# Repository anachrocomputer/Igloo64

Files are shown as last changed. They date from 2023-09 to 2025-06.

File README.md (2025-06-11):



# Igloo64 #

PCB design to adapt a 64-pin TQFP part to a standard solderless breadboard.

## The Problem ##

Many modern chips are only available in surface-mount packages.
Some have the audacity to have 64 pins, and not only that, pins on all four sides.
How can we make such a heinous package fit onto a standard solderless breadboard?

## The Solution ##

This PCB design mounts the SMD part on a vertical board that plugs into a second board
that fits on the breadboard.
The vertical board has a rounded top, reminiscent of an igloo, hence the name.

## KiCad ##

This design has been created using the Open Source CAD package KiCad, V8.0.

To install it on Ubuntu Linux:

`sudo add-apt-repository ppa:kicad/kicad-8.0-releases`

`sudo apt update`

`sudo apt install kicad`

I'm using Ubuntu 22.04 LTS which would give me the very outdated KiCad V6.0 by default.
As I write this, the latest KiCad is V8.0.5,
which is a big upgrade from the V6.0 which I started with.

## PCB Screenshot ##
Work-in-progress, showing routed tracks.
The main TQFP footprint and the four connectors surrounding it have been rotated by
45 degrees before the tracks were routed to the connectors at the bottom.
Those tracks are still a bit uneven, but they all connect correctly.
Space at the curved top of the board may be adorned with LEDs,
the bigger the better.

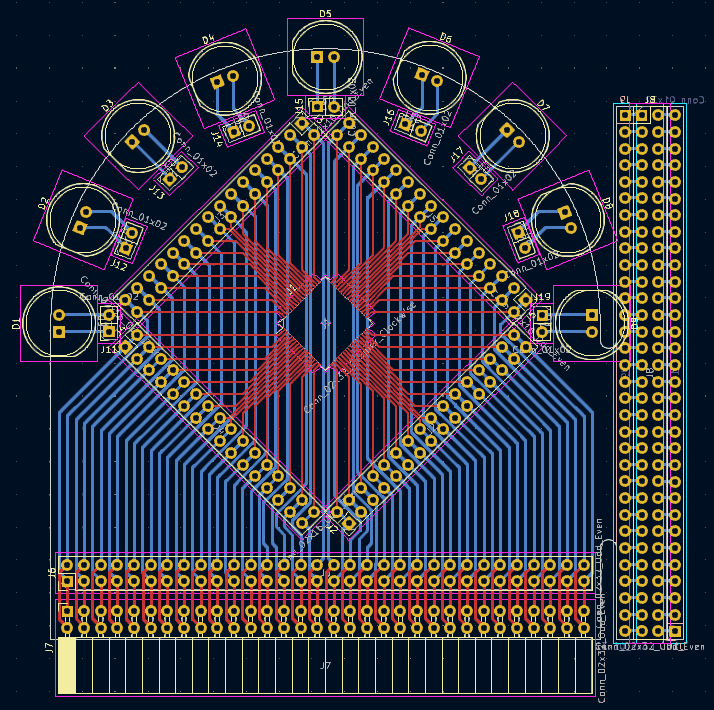
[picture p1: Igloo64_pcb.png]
PCB screenshot


## PCB 3D Render ##
KiCad's 3D rendering of the PCB as it is so far.
The portion on the right-hand side will be snapped off using mouse-bites and used
to connect the main board to the solderless breadboard.
Any colour LEDs may be fitted, up to 10mm in diameter.
The user may choose to use female headers instead of male ones,
or simply not fit headers at all if they're not needed.
Brightly coloured headers are also optional.

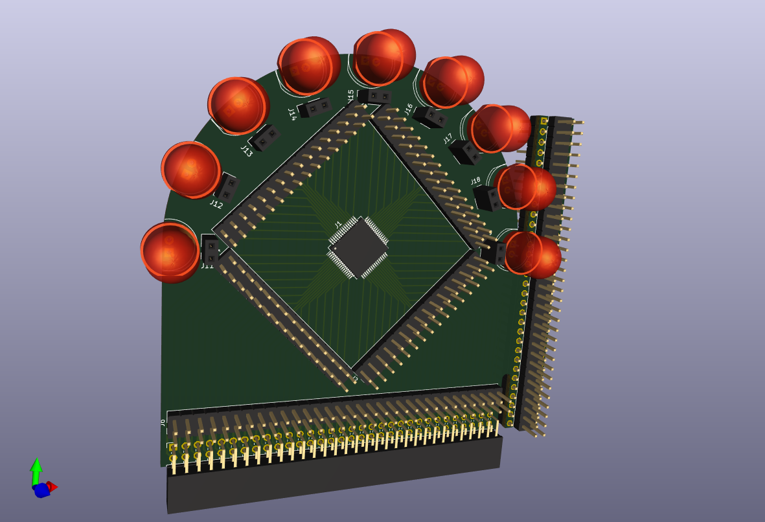
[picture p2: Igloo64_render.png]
PCB render


## PCB Photo ##
Photo of the PCB, as manufactured.

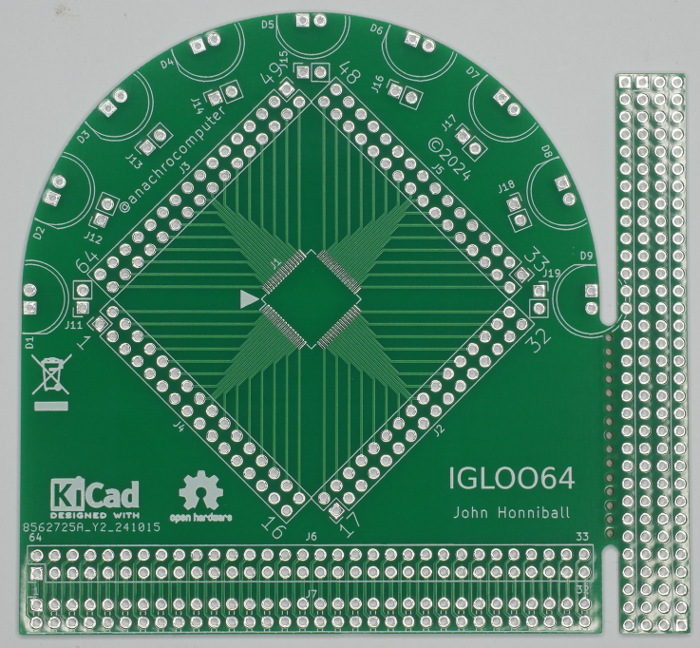
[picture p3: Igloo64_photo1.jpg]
PCB photo


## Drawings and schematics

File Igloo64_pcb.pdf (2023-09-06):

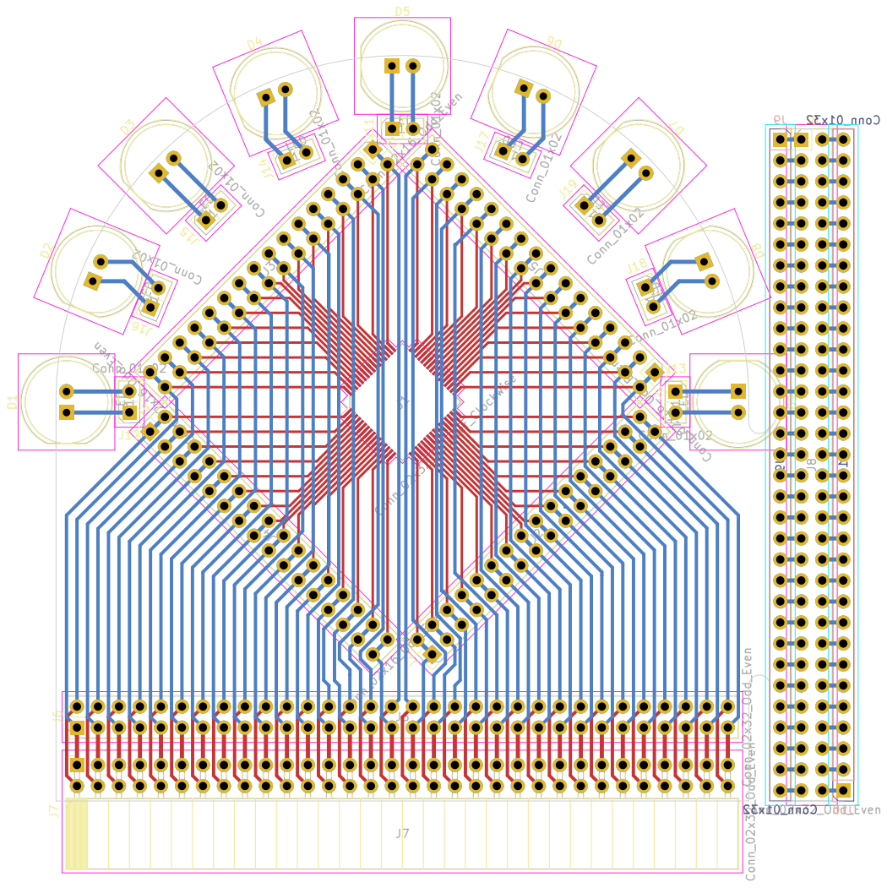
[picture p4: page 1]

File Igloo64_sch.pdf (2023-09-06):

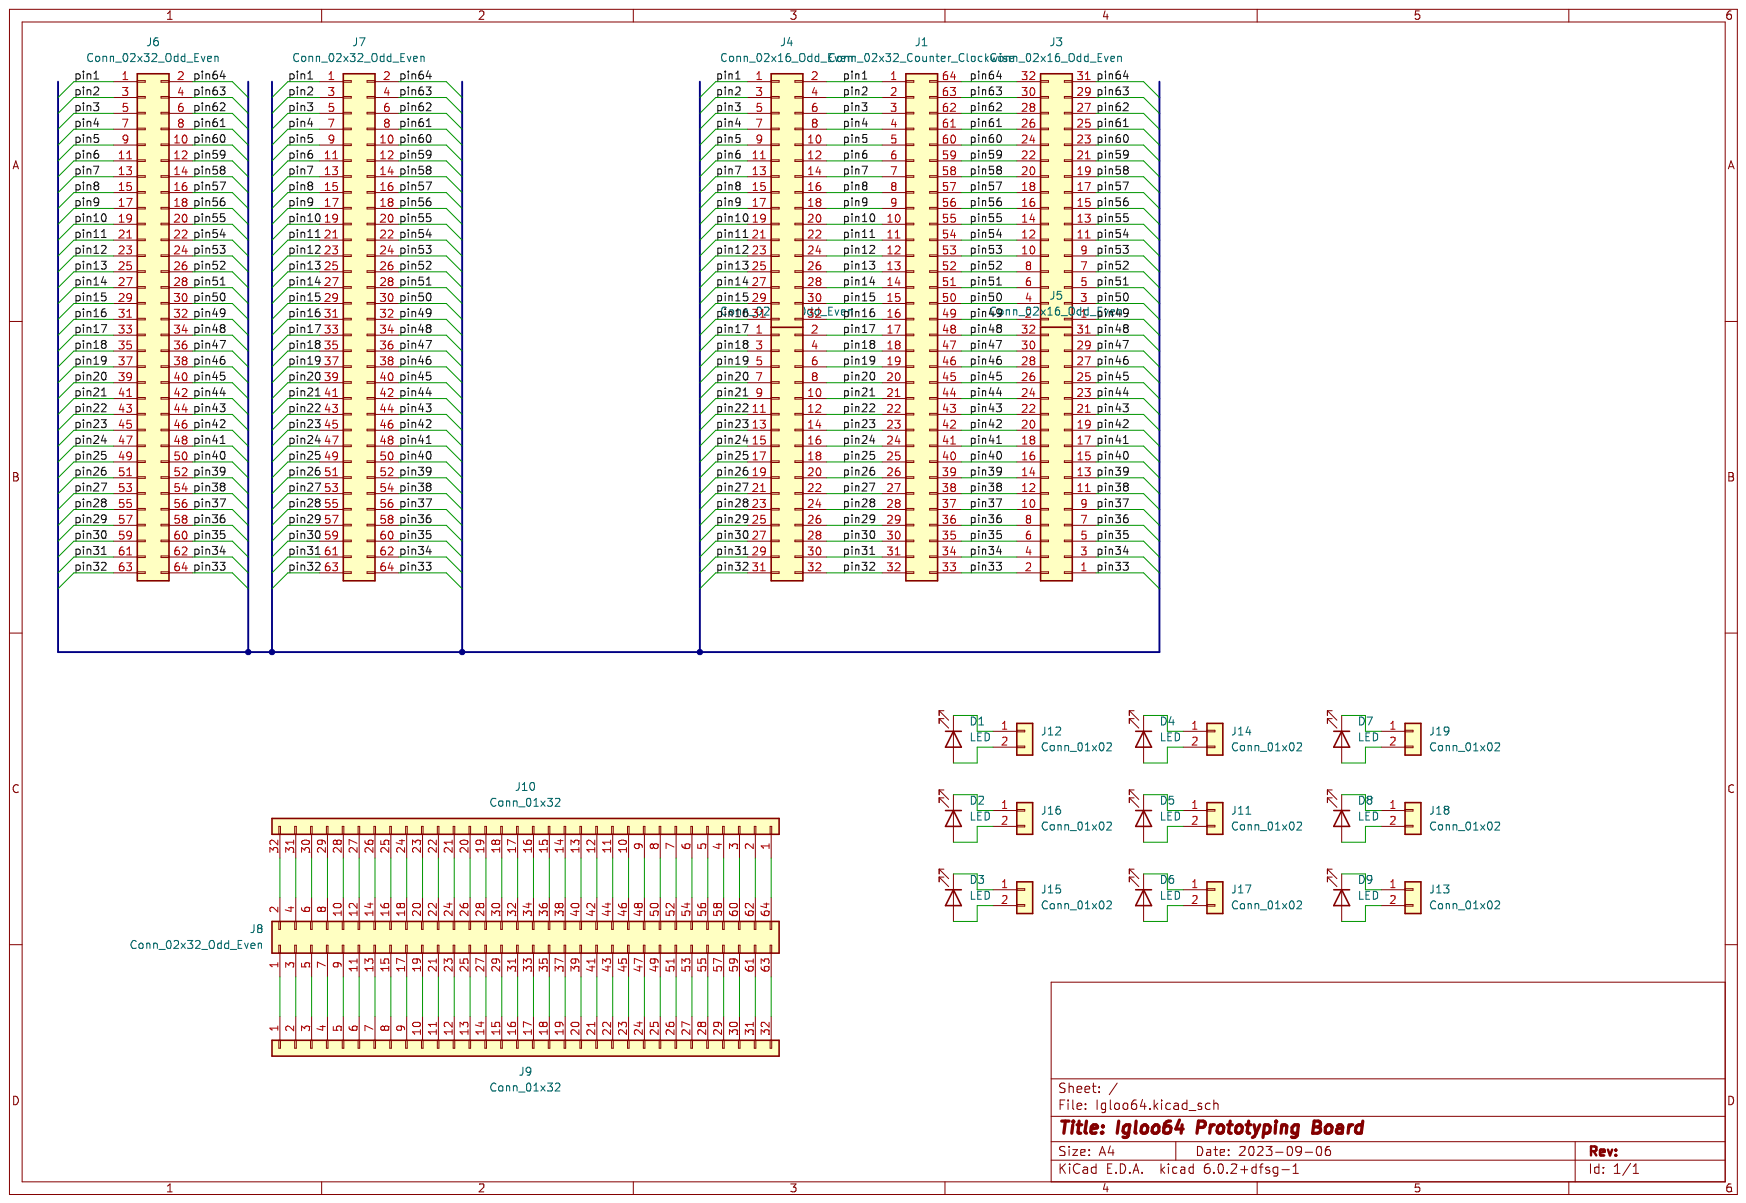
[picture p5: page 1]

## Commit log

2023-08-28 Initial commit.
    Schematic incomplete. PCB design looks OK but TQFP footprint is not in the best orientation. Secondary PCB not yet added.
    [Igloo64.kicad_pcb, Igloo64.kicad_sch]
2023-08-29 Finish wiring of buses.
    Also rotate TQFP footprint temporarily and move headers closer to it. Add tracks from TQFP to header on one side only to see how well it can be routed.
    [Igloo64.kicad_pcb, Igloo64.kicad_sch]
2023-08-29 Add secondary PCB and double up connectors.
    The secondary PCB plugs into the solderless breadboard in the same way as a 64-pin DIL chip (0.3in width). It's just connectors. Also make the ring of connectors around the TQFP footprint into 2-row 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
    [Igloo64.kicad_pcb, Igloo64.kicad_sch]
2023-08-29 Add screenshot of PCB in editor.
2023-08-29 Add PDF files for users to preview.
    Also useful for users who have not (yet) installed KiCad.
2023-09-05 Rotate TQFP and route all tracks.
    But I had to make the board wider to allow the tracks near J6 and J7 to be routed. Some rear tracks still a bit uneven and asymmetrical. Needs proper mouse bites.
    [Igloo64.kicad_pcb]
2023-09-05 Switch PDF to colour, as it was before.
    Also add border and title block, and update datestamp.
    [Igloo64.kicad_pcb]
2023-09-06 Add nine big LEDs.
    Place nine 10mm LEDs around the curved upper edge of the PCB. There's just enough room for the LEDs and the two-pin headers to connect them up. Also fix the width of one track that was too narrow.
    [Igloo64.kicad_pcb, Igloo64.kicad_sch]
2023-09-07 Renumber LED connectors.
    Also remove unconnected track on /pin49.
    [Igloo64.kicad_pcb, Igloo64.kicad_sch]
2024-09-27 Big upgrade to KiCad V8.0.5.
    Original design was done with the default KiCad that comes with Ubuntu 22.04 LTS, V6.0. But things have moved on, and I want to use the latest version. Automatic upgrade seemed to go OK. Skip V7.0 altogether.
    [Igloo64.kicad_pcb, Igloo64.kicad_sch]
2024-10-14 Update schematic to V1.0 and today's date.
    [Igloo64.kicad_sch]
2024-10-14 Add tear-off perforations.
    New footprint with five 1mm non-PTH holes. But it'll never tear along the perforations...
    [Igloo64.kicad_pcb]
2024-10-14 Clean up silkscreen.
    Move designators within PCB. Remove three that we just don't have room for.
    [Igloo64.kicad_pcb]
2024-10-14 Fix DRC error.
    One track too close to pin. Evened out some of the rear tracks for neatness.
    [Igloo64.kicad_pcb]
2024-10-14 Add silkscreen information.
    Pin 1 arrow, logos, names, pin numbers, copyright date.
    [Igloo64.kicad_pcb]
2024-11-20 Add photo of finished board.
    Remove dire warning.
2025-06-14 Minor changes after generating CAM files.
    [Igloo64.kicad_pcb]
2025-06-14 Duplicate entire design with 0.8mm pitch TQFP-64.
    Original design had 0.5mm pitch TQFP-64, but some chips are just that little bit bigger, e.g. ATmega2561.
    [Igloo64_08.kicad_pcb, Igloo64_08.kicad_sch]
